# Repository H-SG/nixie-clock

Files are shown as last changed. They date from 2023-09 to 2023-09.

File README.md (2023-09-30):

# Nixie Clock
Since I first discovered Nixie tubes in the early 2000s I've been fascinated by them and have always wanted to own a Nixie clock. Well, what better way than to build one yourself? Due to cost and cuteness, I've gone with the smallest Nixie tubes commonly available, IN-17s.

I seriously started doing the design for this around 2017 to distract myself from my thesis, and after making a rudimentary PCB in Eagle and a 2 tube breadboard prototype the project languished until 2023.

## Design
I'm going for a sandwich PCB design which I can do in stages to play around with various control schemes and other options. I'm going for a relatively standard approach of 74141 drivers, 74595 shift registeres, high side anode control for dimming, and an Arduino running it all with a mostly through-hole design. There are better ways with more modern components, but I'm doing this for A E S T H E T I C.

### Board 1 - Nixie Drivers
The first (and so far only) PCB made, this is where the Nixie tubes are soldered to along with the driver chips and anode current limiting resistors. I've had to make a few custom footprints in kicad since Eagle has gone the way of the dodo, but I really enjoyed this process.

Future revisions will probalby include the following improvements:
* Tighter layout of tubes
* Some rail capacitance
* Silkscreen on back?

## Code
It's relatively straightforward.
1. Get time from RTC module
2. Shift out time to 74595s
3. Do some fun dimming control
4. Repeat

I almost did some nasty stuff with pointers, and then decided I don't need that in my life. I might look at increasing PWM frequency for brightness control in future, but currently it works quite well.

## References
I stand on the shoulders of others, here are all the references I used for this project:
* [Dalibor's guidance on preventing cathode poisoning](https://www.manula.com/manuals/daliborfarny-com/nixie-tubes/1/en/topic/cathode-poisoning-prevention-routine)
* [High side driving with optoisolators](https://www.microfarad.de/nixie-clock/#gallery-10)
* [TLP627 datasheet](https://www.soemtron.org/downloads/disposals/tlp627.pdf)
    * [Local supplier](https://www.mantech.co.za/ProductInfo.aspx?Item=35M5983)
* [High side driving with MPSA92 & 42](https://reipooom.files.wordpress.com/2011/08/nixie-clock-from-jameco1.pdf)
    * [More arguments about this](https://electronics.stackexchange.com/questions/331220/anode-driver-for-nixie-clock)
* [Reference info on IN-17](https://www.swissnixie.com/tubes/IN17/)
* [Shift registers on Arduino](https://docs.arduino.cc/tutorials/communication/guide-to-shift-out)
* [Possible source for Soviet era 74141 drivers](https://tubehobby.com/show_det.php?det=35)
    * These use 2.5mm pinspacing instead of 2.54mm (1mili)
    * Modern sources are Integral from Belarus...

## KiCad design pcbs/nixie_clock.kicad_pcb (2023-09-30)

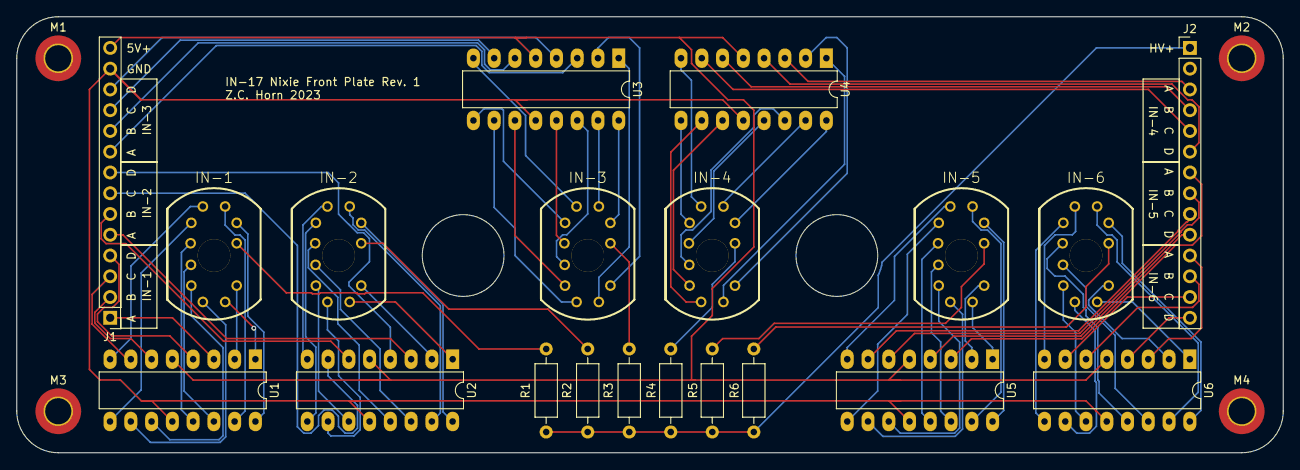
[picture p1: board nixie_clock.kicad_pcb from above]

Board: 2 copper layers, 154.9 x 53.3 mm, 24 parts (0 on the bottom side), 93 nets.

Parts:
IN-1, IN-2, IN-3, IN-4, IN-5, IN-6: nixies-us-IN-17
J1, J2: Conn_01x14_Pin; PinHeader_1x14_P2.54mm_Vertical
M1, M2, M3, M4: MountingHole_3.2mm_M3_DIN965_Pad_TopBottom
R1, R2, R3, R4, R5, R6: 22k; R_Axial_DIN0207_L6.3mm_D2.5mm_P10.16mm_Horizontal
U1, U2, U3, U4, U5, U6: 74141; DIP-16_W7.62mm_LongPads

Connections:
/Vcc: J1.14, U1.5 (VCC), U2.5 (VCC), U3.5 (VCC), U4.5 (VCC), U5.5 (VCC), U6.5 (VCC)
/gnd: J1.13, U1.12 (GND), U2.12 (GND), U3.12 (GND), U4.12 (GND), U5.12 (GND), U6.12 (GND)
/hv1: IN-1.A, R1.1
/hv2: IN-2.A, R2.1
/hv3: IN-3.A, R3.1
/hv4: IN-4.A, R4.2
/hv5: IN-5.A, R5.2
/hv6: IN-6.A, R6.2
/nixie-anodes: J2.1, R1.2, R2.2, R3.2, R4.1, R5.1, R6.1
unnamed: J1.1, U1.3 (A)
unnamed: J1.2, U1.6 (B)
unnamed: J1.3, U1.7 (C)
unnamed: J1.4, U1.4 (D)
unnamed: J1.5, U2.3 (A)
unnamed: J1.6, U2.6 (B)
unnamed: J1.7, U2.7 (C)
unnamed: J1.8, U2.4 (D)
unnamed: J1.9, U3.3 (A)
unnamed: J1.10, U3.6 (B)
unnamed: J1.11, U3.7 (C)
unnamed: J1.12, U3.4 (D)
unnamed: J2.3, U4.3 (A)
unnamed: J2.4, U4.6 (B)
unnamed: J2.5, U4.7 (C)
unnamed: J2.6, U4.4 (D)
unnamed: J2.7, U5.3 (A)
unnamed: J2.8, U5.6 (B)
unnamed: J2.9, U5.7 (C)
unnamed: J2.10, U5.4 (D)
unnamed: J2.11, U6.3 (A)
unnamed: J2.12, U6.6 (B)
unnamed: J2.13, U6.7 (C)
unnamed: J2.14, U6.4 (D)
unnamed: IN-1.0, U1.16 (~Q0)
unnamed: IN-1.1, U1.15 (~Q1)
unnamed: IN-1.2, U1.8 (~Q2)
unnamed: IN-1.3, U1.9 (~Q3)
unnamed: IN-1.4, U1.13 (~Q4)
unnamed: IN-1.5, U1.14 (~Q5)
unnamed: IN-1.6, U1.11 (~Q6)
unnamed: IN-1.7, U1.10 (~Q7)
unnamed: IN-1.8, U1.1 (~Q8)
unnamed: IN-1.9, U1.2 (~Q9)
unnamed: IN-2.0, U2.16 (~Q0)
unnamed: IN-2.1, U2.15 (~Q1)
unnamed: IN-2.2, U2.8 (~Q2)
unnamed: IN-2.3, U2.9 (~Q3)
unnamed: IN-2.4, U2.13 (~Q4)
unnamed: IN-2.5, U2.14 (~Q5)
unnamed: IN-2.6, U2.11 (~Q6)
unnamed: IN-2.7, U2.10 (~Q7)
unnamed: IN-2.8, U2.1 (~Q8)
unnamed: IN-2.9, U2.2 (~Q9)
unnamed: IN-3.0, U3.16 (~Q0)
unnamed: IN-3.1, U3.15 (~Q1)
unnamed: IN-3.2, U3.8 (~Q2)
unnamed: IN-3.3, U3.9 (~Q3)
unnamed: IN-3.4, U3.13 (~Q4)
unnamed: IN-3.5, U3.14 (~Q5)
unnamed: IN-3.6, U3.11 (~Q6)
unnamed: IN-3.7, U3.10 (~Q7)
unnamed: IN-3.8, U3.1 (~Q8)
unnamed: IN-3.9, U3.2 (~Q9)
unnamed: IN-4.0, U4.16 (~Q0)
unnamed: IN-4.1, U4.15 (~Q1)
unnamed: IN-4.2, U4.8 (~Q2)
unnamed: IN-4.3, U4.9 (~Q3)
unnamed: IN-4.4, U4.13 (~Q4)
unnamed: IN-4.5, U4.14 (~Q5)
unnamed: IN-4.6, U4.11 (~Q6)
unnamed: IN-4.7, U4.10 (~Q7)
unnamed: IN-4.8, U4.1 (~Q8)
unnamed: IN-4.9, U4.2 (~Q9)
unnamed: IN-5.0, U5.16 (~Q0)
unnamed: IN-5.1, U5.15 (~Q1)
unnamed: IN-5.2, U5.8 (~Q2)
unnamed: IN-5.3, U5.9 (~Q3)
unnamed: IN-5.4, U5.13 (~Q4)
unnamed: IN-5.5, U5.14 (~Q5)
unnamed: IN-5.6, U5.11 (~Q6)
unnamed: IN-5.7, U5.10 (~Q7)
unnamed: IN-5.8, U5.1 (~Q8)
unnamed: IN-5.9, U5.2 (~Q9)
unnamed: IN-6.0, U6.16 (~Q0)
unnamed: IN-6.1, U6.15 (~Q1)
unnamed: IN-6.2, U6.8 (~Q2)
unnamed: IN-6.3, U6.9 (~Q3)
unnamed: IN-6.4, U6.13 (~Q4)
unnamed: IN-6.5, U6.14 (~Q5)
unnamed: IN-6.6, U6.11 (~Q6)
unnamed: IN-6.7, U6.10 (~Q7)
unnamed: IN-6.8, U6.1 (~Q8)
unnamed: IN-6.9, U6.2 (~Q9)

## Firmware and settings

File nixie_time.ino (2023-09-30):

#include <Wire.h>
#include "RTClib.h"
#include "LinkedList.h"

// hardware vars and others
RTC_DS3231 rtc;
int brightP = 10;
int latchP = 11;
int clockP = 12;
int dataP = 13;
unsigned long current_time;
DateTime now;

// levels for brightness cycles, levels are precomputed
LinkedList<int> brightnessLevels = LinkedList<int>();
int b[50] = {128, 143, 159, 174, 189, 202, 215, 226, 235, 243, 
             248, 252, 254, 254, 252, 248, 242, 234, 225, 214,
             202, 188, 174, 158, 143, 127, 111, 95, 80, 65,
             52, 40, 29, 20, 12, 6, 3, 1, 1, 3,
             7, 13, 21, 31, 42, 54, 68, 82, 98, 113};

void setup() {
  rtc.begin();
  // unset this to update time from system
  // rtc.adjust(DateTime(F(__DATE__), F(__TIME__)));

  // set out pinmodes
  pinMode(latchP, OUTPUT);
  pinMode(clockP, OUTPUT);
  pinMode(dataP, OUTPUT);
  pinMode(LED_BUILTIN, OUTPUT);

  // debug serial
  // Serial.begin(9600);

  // initialise linked list
  for (int i = 0; i < 50; i++) {
    brightnessLevels.add(b[i]);
  }

  // run antipoison as startup animation
  antiPoison(100, 2000);

  // set brightness to median
  analogWrite(brightP, 128);

  // initialise time
  current_time = millis();
  now = rtc.now();
}

void loop() {
  // get current time from rtc and write it out
  now = rtc.now();
  timeWrite(now);

  // check if millis has rolled over
  if (millis() < current_time) {
    current_time = millis();
  }

  // brightness pulse routine 40 ms delay should result in full pulse cycle over 2 seconds
  if (millis() - current_time >= 40) {
    int current_brightness = brightnessLevels.shift();
    brightnessLevels.add(current_brightness);
    analogWrite(brightP, current_brightness);
    current_time += 40;
  }


  // run anti-poison routine at 01:00:00
  if (now.hour() == 1) {
    if (now.minute() == 0) {
      if (now.second() == 0) {
        antiPoison(0, 300000);
        current_time += 300000;
      }
    }
  }
}

void timeWrite(DateTime passed_time){
  // disable output so we don't see flickering garbage
  digitalWrite(latchP, LOW);
  // each shiftout controls two digits of the clock
  shiftOut(dataP, clockP, MSBFIRST, numToShiftNum(passed_time.second()));
  shiftOut(dataP, clockP, MSBFIRST, numToShiftNum(passed_time.minute()));
  shiftOut(dataP, clockP, MSBFIRST, numToShiftNum(passed_time.hour()));
  // enable output now that shiftout is done
  digitalWrite(latchP, HIGH);
}

void antiPoison(unsigned int delayTime, unsigned long runTime){
  // implements carousel effect for cathode poisoning prevention
  // better would be to track on time for various digits and then 
  // run the rest as needed
  unsigned long start_time = millis();
  analogWrite(brightP, 255);
  while ((millis() - start_time) < runTime) {
    for (int i = 0; i <= 9; i++){
      int output = (i << 4) + i;
      digitalWrite(latchP, LOW);
      shiftOut(dataP, clockP, MSBFIRST, output);
      shiftOut(dataP, clockP, MSBFIRST, output);
      shiftOut(dataP, clockP, MSBFIRST, output);
      digitalWrite(latchP, HIGH);
      delay(delayTime);
    }

    // handle rollover behaviour
    if (millis() < start_time) {
      break;
    }
  }
  analogWrite(brightP, 1);
}

int numToShiftNum(unsigned int num){
  // shiftOut can do max 255, so we limit this to two digits (two 4 bit pairs)
  int digit2 = num % 10;
  int digit1 = (num - digit2)/10;
  int output = digit2 << 4;
  output += digit1;
  return output;
}
